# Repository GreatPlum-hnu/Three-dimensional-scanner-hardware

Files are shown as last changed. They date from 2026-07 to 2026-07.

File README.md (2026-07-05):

# 三维重建硬件资料说明

本目录内容用于个人学习、研究和自用记录，主要整理手持式激光雷达与相机融合三维重建相关的硬件清单、连接关系和选型备注。

## 使用声明

- 本项目仅供个人学习、实验和资料整理使用，不用于商业用途。
- 文档中的品牌、型号、链接和资料名称仅用于说明硬件选型和技术参考，不代表与相关品牌或厂商存在合作关系。
- 文档中的价格、链接和参数可能会随时间变化，实际采购前请以官方资料、商家页面和设备手册为准。
- 如文档中引用或整理的资料未正确标注来源，或涉及版权、署名、链接失效等问题，请联系作者，我会及时补充来源、修改内容或删除相关信息。

## 内容范围

- 三维重建硬件清单
- 雷达、相机、同步器、供电、支架和外壳等选型记录
- 系统连接关系和采购注意事项
- 相关官方资料和参考链接

## 文档阅读顺序

1. [三维重建硬件清单](三维重建硬件清单.md)
2. [FAST-LIVO2 前端建图环境安装教程（fishros 版）](FAST-LIVO2前端建图环境安装教程-fishros版.md)
3. [FAST-LIVO2 前端建图硬件同步器与驱动安装（MID360 版）](FAST-LIVO2前端建图硬件同步器与驱动安装-MID360版.md)
4. [FAST-LIVO2 前端建图相机内参与雷达相机外参标定教程](FAST-LIVO2前端建图相机内参与雷达相机外参标定教程.md)
5. [FAST-LIVO2 输出数据导入 Postshot 高斯泼溅重建教程](FAST-LIVO2输出数据导入Postshot高斯泼溅重建教程.md)

## 一键启动

完成环境安装、驱动配置、相机内参标定和雷达-相机外参标定后，可以使用启动脚本：

```bash
./scripts/start_fast_livo_mid360.sh
```

当前默认使用 `mapping_avia.launch` 做启动测试。正式 MID360 三维重建时，应将 `FAST_LIVO_LAUNCH` 设置为已经完成标定配置的 MID360 launch 文件。

## 免责声明

本文档不构成产品推荐、采购承诺或工程交付文件。实际搭建、接线、供电和调试过程中，请遵守设备厂商说明，确认电压、电流、线序、极性和接口兼容性。因自行使用本文档内容造成的设备损坏、数据损失或其他风险，由使用者自行承担。

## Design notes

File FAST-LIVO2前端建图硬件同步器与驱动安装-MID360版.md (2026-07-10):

# FAST-LIVO2 前端建图硬件同步器与驱动安装教程（MID360 版）

本文档基于 `scan2.world` 的 FAST-LIVO2 手持三维重建设备教程 2 重新整理，只保留 Livox MID360 相关内容。

本版不包含 AVIA、Livox-SDK、livox_ros_driver 的安装流程。MID360 应使用：

- Livox-SDK2
- livox_ros_driver2
- ROS1 Noetic
- Hikrobot MVS / mvs_ros_driver

本文档优先使用 `LIV_handhold` 中的 `livox_ros_driver2` 和 `mvs_ros_driver`，因为该仓库的驱动包含面向 FAST-LIVO2 手持三维重建设备的硬件同步适配。官方 `Livox-SDK/livox_ros_driver2` 可用于 MID360 基础点云测试，但不能替代相机驱动和整套同步方案。

## 一、准备内容

建议先完成上一篇环境安装：

- Ubuntu 20.04
- ROS Noetic
- FAST-LIVO2 工作空间
- Catkin 编译环境

硬件侧准备：

- Livox MID360
- 海康工业相机
- 硬件同步器
- MID360 网线 / 一分三线缆
- 相机 USB 线
- 稳定供电模块

## 二、硬件同步器制作说明

原教程的硬件同步器制作过程主要通过图片展示。整理为 MID360 版本时，重点保留以下连接关系：

- MID360：通过网口连接主机，通过供电线接入电源。
- 海康相机：通过 USB 连接主机，通过触发线接入同步器。
- 同步器：负责给相机提供外部触发信号，并与系统供电共地。
- 主机：同时接收 MID360 的点云 / IMU 数据和相机图像数据。

制作和接线时请重点确认：

- 电源电压和电流满足 MID360、相机和同步器要求。
- GND 必须共地。
- 相机触发线极性正确。
- MID360 使用网口通信，不使用 AVIA 的串口配置方式。
- 所有线序以设备手册、同步器原理图和实际接口定义为准。

## 三、安装海康 MVS 驱动

到海康机器人官网下载对应 Linux 版本的 MVS 客户端和 SDK：

```text
https://www.hikrobotics.com/cn/machinevision/service/download/?module=0
```

安装完成后，可以进入 MVS 目录测试软件是否能打开：

```bash
cd /opt/MVS/bin
export LD_LIBRARY_PATH=/opt/MVS/bin/:$LD_LIBRARY_PATH
./MVS
```

如果 `./MVS` 无法启动，也可以尝试：

```bash
./MVS.sh
```

确认 MVS 能识别相机后，再继续配置 ROS 驱动。

注意：使用 ROS 驱动打开相机前，请关闭 MVS 客户端，避免相机被 MVS 占用导致 ROS 驱动无法打开设备。

## 四、安装 Livox-SDK2

MID360 使用 Livox-SDK2，不使用 Livox-SDK。

先确认基础编译工具已安装：

```bash
sudo apt update
sudo apt install -y git cmake build-essential
```

执行：

```bash
cd ~
git clone https://github.com/Livox-SDK/Livox-SDK2.git
cd Livox-SDK2
mkdir -p build
cd build
cmake ..
make -j$(nproc)
sudo make install
sudo ldconfig
```

如果电脑内存较小，可以将 `make -j$(nproc)` 改为：

```bash
make -j2
```

如果后续启动驱动时提示找不到 Livox SDK2 的动态库，可以临时执行：

```bash
export LD_LIBRARY_PATH=${LD_LIBRARY_PATH}:/usr/local/lib
```

也可以写入 `~/.bashrc`：

```bash
echo 'export LD_LIBRARY_PATH=${LD_LIBRARY_PATH}:/usr/local/lib' >> ~/.bashrc
source ~/.bashrc
```

## 五、下载 MID360 和相机 ROS 驱动

本文档统一使用已有的 `~/catkin_ws` 作为 ROS1 工作空间。进入工作空间 `src` 目录：

```bash
mkdir -p ~/catkin_ws/src
cd ~/catkin_ws/src
```

下载三维重建手持设备驱动仓库：

```bash
git clone https://github.com/xuankuzcr/LIV_handhold.git
```

如果仓库中已经包含 `livox_ros_driver2` 和 `mvs_ros_driver`，将它们移动到当前工作空间的 `src` 下：

```bash
mv LIV_handhold/livox_ros_driver2 ./
mv LIV_handhold/mvs_ros_driver ./
```

如果该仓库内容发生变化，也可以直接下载官方 MID360 驱动：

```bash
git clone https://github.com/Livox-SDK/livox_ros_driver2.git
```

注意：官方 `livox_ros_driver2` 只能补充雷达 ROS 驱动，不能提供 `mvs_ros_driver`。相机 ROS 驱动仍需要从 `LIV_handhold` 或后续官方同步器配套仓库中获取。

目录建议保持为：

```text
catkin_ws
└── src
    ├── livox_ros_driver2
    └── mvs_ros_driver
```

## 六、编译 MID360 和相机 ROS 驱动

MID360 的 `livox_ros_driver2` 同时支持 ROS1 和 ROS2。ROS Noetic 下要明确使用 ROS1。

优先使用 `livox_ros_driver2` 的构建脚本。该脚本会回到工作空间根目录执行 `catkin_make`，因此同一工作空间中的 `mvs_ros_driver` 也会一起编译：

```bash
cd ~/catkin_ws/src/livox_ros_driver2
source /opt/ros/noetic/setup.bash
./build.sh ROS1
```

如果你使用的驱动包要求在工作空间根目录编译，建议只编译驱动相关包，避免同一工作空间中的其他包影响本步骤：

```bash
cd ~/catkin_ws
catkin_make -DROS_EDITION=ROS1 -DCATKIN_WHITELIST_PACKAGES="livox_ros_driver2;mvs_ros_driver"
```

编译完成后，如果后续需要恢复整个工作空间编译，可以清空白名单：

```bash
catkin_make -DCATKIN_WHITELIST_PACKAGES=""
```

如果后续要运行 FAST-LIVO2，还需要把 FAST-LIVO2 及其依赖包一起编译。由于当前工作空间中的 `livox_camera_calib` 可能会因为 PCL / libusb 链接问题影响整体编译，可以继续使用白名单方式，跳过 `livox_camera_calib`：

```bash
cd ~/catkin_ws
catkin_make -DROS_EDITION=ROS1 -DCATKIN_WHITELIST_PACKAGES="livox_ros_driver2;mvs_ros_driver;vikit_common;vikit_ros;vikit_py;fast_livo"
```

编译完成后加载环境：

```bash
source ~/catkin_ws/devel/setup.bash
```

检查两个 ROS 包是否都能被找到：

```bash
rospack find livox_ros_driver2
rospack find mvs_ros_driver
```

建议写入 `~/.bashrc`：

```bash
echo "source ~/catkin_ws/devel/setup.bash" >> ~/.bashrc
source ~/.bashrc
```

## 七、配置 MID360 网络

MID360 使用静态 IP。常见规则是：

```text
MID360 IP: 192.168.1.1XX
```

其中 `XX` 通常对应 MID360 序列号最后两位。比如序列号最后两位是 `02`，设备 IP 可能是：

```text
192.168.1.102
```

主机有线网卡需要设置到同一网段，例如：

```text
IP 地址:   192.168.1.5
子网掩码: 255.255.255.0
网关:     192.168.1.1
```

设置完成后，测试是否能 ping 通 MID360：

```bash
ping 192.168.1.102
```

请把 `192.168.1.102` 替换为你的 MID360 实际 IP。

## 八、修改 MID360 配置文件

配置文件通常位于：

```bash
~/catkin_ws/src/livox_ros_driver2/config/MID360_config.json
```

需要重点修改两类 IP：

- `host_net_info`：主机有线网卡 IP，例如 `192.168.1.5`
- `lidar_configs`：MID360 的实际 IP，例如 `192.168.1.102`

典型配置片段如下：

```json
{
  "lidar_summary_info": {
    "lidar_type": 8
  },
  "MID360": {
    "lidar_net_info": {
      "cmd_data_port": 56100,
      "push_msg_port": 56200,
      "point_data_port": 56300,
      "imu_data_port": 56400,
      "log_data_port": 56500
    },
    "host_net_info": {
      "cmd_data_ip": "192.168.1.5",
      "cmd_data_port": 56101,
      "push_msg_ip": "192.168.1.5",
      "push_msg_port": 56201,
      "point_data_ip": "192.168.1.5",
      "point_data_port": 56301,
      "imu_data_ip": "192.168.1.5",
      "imu_data_port": 56401,
      "log_data_ip": "",
      "log_data_port": 56501
    }
  },
  "lidar_configs": [
    {
      "ip": "192.168.1.102",
      "pcl_data_type": 1,
      "pattern_mode": 0,
      "extrinsic_parameter": {
        "roll": 0.0,
        "pitch": 0.0,
        "yaw": 0.0,
        "x": 0,
        "y": 0,
        "z": 0
      }
    }
  ]
}
```

注意：

- 不要把 AVIA 的 `broadcast_code` 配置方式用于 MID360。
- MID360 主要改 IP，不是改序列号。
- 多个 MID360 时，需要在 `lidar_configs` 中添加多个设备配置。

下面以我的电脑为例，说明实际需要检查哪些文件。

我的 `livox_ros_driver2` 放在下面这个工作空间：

```bash
~/catkin_ws/src/livox_ros_driver2
```

如果只使用一台 MID360，主要会用到下面几个 launch 文件：

```text
~/catkin_ws/src/livox_ros_driver2/launch_ROS1/msg_MID360.launch
~/catkin_ws/src/livox_ros_driver2/launch_ROS1/rviz_MID360.launch
~/catkin_ws/src/livox_ros_driver2/launch_ROS1/mid360.launch
```

打开这几个 launch 文件，可以看到它们都引用同一个配置文件：

```text
$(find livox_ros_driver2)/config/MID360_config.json
```

所以单 MID360 方案真正需要重点检查的是：

```bash
~/catkin_ws/src/livox_ros_driver2/config/MID360_config.json
```

以我的电脑为例，`MID360_config.json` 中的主机 IP 已经改成 `192.168.1.4`：

```json
"host_net_info": {
  "cmd_data_ip": "192.168.1.4",
  "push_msg_ip": "192.168.1.4",
  "point_data_ip": "192.168.1.4",
  "imu_data_ip": "192.168.1.4"
}
```

这里的 `192.168.1.4` 是我的电脑连接 MID360 所在网段的 IP。你实际配置时，需要改成你自己电脑连接 MID360 的网卡 IP。

同一个文件中，MID360 雷达 IP 已经改成 `192.168.1.165`：

```json
"lidar_configs": [
  {
    "ip": "192.168.1.165"
  }
]
```

再检查 launch 文件中的序列号。以我的 MID360 为例，序列号是 `47MCNCP0036165`：

```xml
<arg name="bd_list" default="47MCNCP0036165"/>
```

这个序列号需要在下面几个单 MID360 launch 文件中保持一致：

```text
msg_MID360.launch
rviz_MID360.launch
mid360.launch
```

另外，`mixed_HAP_MID360_config.json` 不是单 MID360 方案的主配置文件。它只在运行混合设备 launch 时使用：

```text
msg_mixed.launch
rviz_mixed.launch
```

所以如果只接一台 MID360，不需要修改 `mixed_HAP_MID360_config.json`。

## 九、修改相机配置文件

相机配置文件通常位于：

```bash
~/catkin_ws/src/mvs_ros_driver/config/left_camera_trigger.yaml
```

检查触发模式和像素格式。

建议重点检查：

```yaml
TopicName: "left_camera/image"
TriggerEnable: 1
```

其中 `TriggerEnable: 1` 表示使用外部触发。如果只是临时测试相机、没有接同步器触发信号，可以改为 `0` 做无触发出图测试，正式录制时再改回 `1`。

原教程中提到，如果使用海康 `MV-CU013-A0UC`，需要将 `PixelFormat` 改为 `4`：

```yaml
PixelFormat: 4
```

常见含义：

```text
0: RGB8
1: BayerRG8
2: BayerRG12Packed
3: BayerGB12Packed
4: BayerGB8
```

如果你的相机型号不同，请以 MVS 中能正常出图的像素格式为准。

## 十、启动 MID360 驱动

加载工作空间：

```bash
source ~/catkin_ws/devel/setup.bash
```

启动 MID360 自定义消息格式驱动：

```bash
roslaunch livox_ros_driver2 msg_MID360.launch
```

如果只是想用 RViz 检查点云显示，可以使用：

```bash
roslaunch livox_ros_driver2 rviz_MID360.launch
```

检查话题：

```bash
rostopic list
```

应能看到类似话题：

```text
/livox/lidar
/livox/imu
```

继续检查话题类型和频率：

```bash
rostopic type /livox/lidar
rostopic type /livox/imu
rostopic hz /livox/lidar
rostopic hz /livox/imu
```

使用 `msg_MID360.launch` 时，`/livox/lidar` 通常应为 `livox_ros_driver2/CustomMsg`。

## 十一、启动海康相机驱动

新开一个终端：

```bash
source ~/catkin_ws/devel/setup.bash
roslaunch mvs_ros_driver mvs_camera_trigger.launch
```

检查相机话题：

```bash
rostopic list | grep camera
```

常见图像话题：

```text
/left_camera/image
```

继续检查图像频率：

```bash
rostopic hz /left_camera/image
```

## 十二、录制 MID360 + 相机数据包

确认 MID360 和相机驱动都启动后，录制 rosbag：

```bash
rosbag record /livox/lidar /livox/imu /left_camera/image
```

也可以指定输出文件名：

```bash
rosbag record -O mid360_livo_data.bag /livox/lidar /livox/imu /left_camera/image
```

录制完成后查看数据包信息：

```bash
rosbag info mid360_livo_data.bag
```

确认其中包含：

```text
/livox/lidar
/livox/imu
/left_camera/image
```

## 十三、验证硬件同步是否生效

录制 bag 包后，可以直接查看雷达和相机话题前两帧的 header 时间戳：

```bash
rostopic echo -b <rosbag_name.bag> -n 2 /livox/lidar/header
rostopic echo -b <rosbag_name.bag> -n 2 /left_camera/image/header

# 如果 bag 中录制的是压缩图像话题，则使用：
rostopic echo -b <rosbag_name.bag> -n 2 /left_camera/image/compressed/header
```

将 `<rosbag_name.bag>` 替换为实际的 bag 文件名，例如 `mid360_livo_data.bag`。对比雷达与相机 header 中的 `stamp` 字段，检查时间戳是否正常且无明显跳变。

如果是在采集现场验证实时硬件同步，可以保持雷达和相机驱动运行，再检查相机触发频率是否稳定：

```bash
rostopic hz /left_camera/image
```

如果同步器输出的是 10 Hz 触发信号，相机图像频率应接近 10 Hz。不同同步器固件或配置的触发频率可能不同，请以实际同步器说明为准。

同步异常时常见现象：

- `/left_camera/image` 没有频率，说明相机没有收到触发信号或触发配置不正确。
- 图像频率明显不稳定，可能是触发线、曝光时间、USB 带宽或相机配置问题。
- 雷达、IMU、图像时间戳存在明显跳变，可能是同步器固件、主机时间或驱动配置问题。

## 十四、运行 FAST-LIVO2

本节中的 FAST-LIVO2 启动仅用于测试环境、驱动、话题和程序是否能跑通。当前还没有完成相机内参标定，也没有完成相机与雷达之间的外参标定，因此这里运行得到的结果只能作为联调参考，不能作为正式三维重建结果。

当前 FAST-LIVO2 工程中还没有 `mapping_mid360.launch`，已有的 launch 文件是官方示例配置。可以先使用 `mapping_avia.launch` 启动，验证 FAST-LIVO2 主程序、雷达话题和相机话题能否跑通。

如果前面只编译了 `livox_ros_driver2` 和 `mvs_ros_driver`，这里需要先确认 FAST-LIVO2 也已经编译：

```bash
cd ~/catkin_ws
catkin_make -DROS_EDITION=ROS1 -DCATKIN_WHITELIST_PACKAGES="livox_ros_driver2;mvs_ros_driver;vikit_common;vikit_ros;vikit_py;fast_livo"
source ~/catkin_ws/devel/setup.bash
```

确认 FAST-LIVO2 包能被 ROS 找到：

```bash
rospack find fast_livo
```

进入 FAST-LIVO2 工作空间环境：

```bash
source ~/catkin_ws/devel/setup.bash
```

查看当前已有 launch 文件：

```bash
ls ~/catkin_ws/src/FAST-LIVO2/launch
```

如果没有 `mapping_mid360.launch`，不要执行：

```bash
roslaunch fast_livo mapping_mid360.launch
```

否则会出现：

```text
RLException: [mapping_mid360.launch] is neither a launch file in package [fast_livo]
```

当前先使用已有的 AVIA 示例 launch 启动：

```bash
roslaunch fast_livo mapping_avia.launch
```

注意：`mapping_avia.launch` 只是当前阶段的启动验证方式，不代表已经完成 MID360 最终适配。它会加载：

```text
~/catkin_ws/src/FAST-LIVO2/config/avia.yaml
~/catkin_ws/src/FAST-LIVO2/config/camera_pinhole.yaml
```

其中 `avia.yaml` 虽然已经使用下面这些话题：

```yaml
img_topic: "/left_camera/image"
lid_topic: "/livox/lidar"
imu_topic: "/livox/imu"
```

但它仍然是 AVIA 示例配置。后续正式使用 MID360 时，需要复制并整理出 MID360 专用配置，例如：

```text
mapping_mid360.launch
mid360.yaml
camera_mid360.yaml
```

并重点确认以下内容已经改成 MID360 对应参数：

- 雷达话题：`/livox/lidar`
- IMU 话题：`/livox/imu`
- 相机话题：`/left_camera/image`
- 雷达到相机外参
- 时间同步参数
- MID360 点云格式
- 相机内参和畸变参数

播放录制好的数据包：

```bash
source ~/catkin_ws/devel/setup.bash
rosbag play mid360_livo_data.bag
```

完成所有配置和标定后，也可以使用项目中的一键启动脚本：

```bash
cd ~/Three-dimensional-scanner-hardware
./scripts/start_fast_livo_mid360.sh
```

如果后续已经创建了正式的 MID360 launch 文件，可以指定：

```bash
FAST_LIVO_LAUNCH=mapping_mid360.launch ./scripts/start_fast_livo_mid360.sh
```

## 十五、常见问题

### 1. 能 ping 通 MID360，但没有点云话题

检查：

- `MID360_config.json` 中主机 IP 是否等于有线网卡 IP。
- `lidar_configs` 中 MID360 IP 是否正确。
- 是否启动了 `msg_MID360.launch`。
- 防火墙是否拦截 UDP 数据。

### 2. 启动驱动时提示找不到 Livox SDK2 动态库

执行：

```bash
export LD_LIBRARY_PATH=${LD_LIBRARY_PATH}:/usr/local/lib
```

然后重新启动驱动。

### 3. catkin_make 编译时报 livox_camera_calib 链接错误

如果执行：

```bash
catkin_make -DROS_EDITION=ROS1
```

出现类似错误：

```text
libpcl_io.so: undefined reference to `libusb_set_option'
livox_camera_calib/CMakeFiles/lidar_camera_calib.dir/all
```

说明当前失败的是 `livox_camera_calib`，不是 `livox_ros_driver2`、`mvs_ros_driver` 或 FAST-LIVO2。可以用白名单跳过 `livox_camera_calib`。

如果只测试驱动，可以只编译驱动相关包：

```bash
cd ~/catkin_ws
catkin_make -DROS_EDITION=ROS1 -DCATKIN_WHITELIST_PACKAGES="livox_ros_driver2;mvs_ros_driver"
source ~/catkin_ws/devel/setup.bash
```

如果还要运行 FAST-LIVO2，需要把 FAST-LIVO2 及其依赖一起加入白名单：

```bash
cd ~/catkin_ws
catkin_make -DROS_EDITION=ROS1 -DCATKIN_WHITELIST_PACKAGES="livox_ros_driver2;mvs_ros_driver;vikit_common;vikit_ros;vikit_py;fast_livo"
source ~/catkin_ws/devel/setup.bash
```

确认驱动包能被找到：

```bash
rospack find livox_ros_driver2
rospack find mvs_ros_driver
rospack find fast_livo
```

`livox_camera_calib` 属于后续雷达-相机外参标定相关内容，可以在需要标定时再单独处理。

### 4. FAST-LIVO2 编译时报 libusb_set_option 链接错误

如果编译 FAST-LIVO2 时出现类似错误：

```text
/usr/bin/ld: .../libpcl_io.so: undefined reference to `libusb_set_option'
collect2: error: ld returned 1 exit status
FAST-LIVO2/CMakeFiles/fastlivo_mapping.dir/all
```

说明 `fastlivo_mapping` 在链接 `libpcl_io.so` 时，没有把 `libusb-1.0` 一起链接进去。`libpcl_io` 内部依赖 libusb，部分 Ubuntu / PCL 组合下这个依赖不会自动传递到最终可执行文件。

先确认 libusb 开发包已经安装：

```bash
sudo apt install -y libusb-1.0-0-dev
pkg-config --libs libusb-1.0
```

正常应输出：

```text
-lusb-1.0
```

然后修改 FAST-LIVO2 的 CMake 配置：

```bash
vim ~/catkin_ws/src/FAST-LIVO2/CMakeLists.txt
```

在 `target_link_libraries(fastlivo_mapping ... )` 中加入：

```cmake
usb-1.0
```

修改后类似：

```cmake
target_link_libraries(fastlivo_mapping
  laser_mapping
  vio
  lio
  pre
  imu_proc
  ${catkin_LIBRARIES}
  ${PCL_LIBRARIES}
  ${OpenCV_LIBRARIES}
  ${Sophus_LIBRARIES}
  ${Boost_LIBRARIES}
  usb-1.0
)
```

重新编译：

```bash
cd ~/catkin_ws
catkin_make -DROS_EDITION=ROS1 -DCATKIN_WHITELIST_PACKAGES="livox_ros_driver2;mvs_ros_driver;vikit_common;vikit_ros;vikit_py;fast_livo"
source ~/catkin_ws/devel/setup.bash
```

### 5. FAST-LIVO2 运行时报 libpcl_io.so undefined symbol

如果执行：

```bash
roslaunch fast_livo mapping_avia.launch
```

启动后 `laserMapping` 立刻退出，并出现类似错误：

```text
/home/zhuzhe/catkin_ws/devel/lib/fast_livo/fastlivo_mapping: symbol lookup error:
/usr/lib/x86_64-linux-gnu/libpcl_io.so.1.10: undefined symbol: libusb_set_option
```

说明运行时加载到了不合适的 `libusb-1.0.so.0`。以我的电脑为例，`LD_LIBRARY_PATH` 中 `/opt/MVS/lib/64` 排在系统库前面，导致 PCL 加载了海康 MVS 自带的 `libusb`，而不是系统自带的 `libusb`。

可以用下面命令检查：

```bash
ldd ~/catkin_ws/devel/lib/fast_livo/fastlivo_mapping | grep libusb
ldd /usr/lib/x86_64-linux-gnu/libpcl_io.so.1.10 | grep libusb
```

如果看到：

```text
libusb-1.0.so.0 => /opt/MVS/lib/64/libusb-1.0.so.0
```

就说明动态库搜索顺序有问题。

临时解决方法是在启动 FAST-LIVO2 的终端中，把系统库路径放到 MVS 路径前面：

```bash
export LD_LIBRARY_PATH=/lib/x86_64-linux-gnu:/usr/lib/x86_64-linux-gnu:/opt/MVS/lib/64:/opt/MVS/lib/32:$LD_LIBRARY_PATH
source ~/catkin_ws/devel/setup.bash
roslaunch fast_livo mapping_avia.launch
```

长期建议：

- 不要在 `~/.bashrc` 中把 `/opt/MVS/lib/64` 放在 `LD_LIBRARY_PATH` 最前面。
- 如果需要配置 MVS 库路径，优先放在系统库路径后面。
- 启动 MVS 客户端和启动 FAST-LIVO2 可以使用不同终端，避免 MVS 的库路径污染 FAST-LIVO2 的运行环境。

### 6. FAST-LIVO2 提示 image has not the same size as the camera model

如果启动 FAST-LIVO2 后出现类似错误：

```text
terminate called after throwing an instance of 'std::runtime_error'
what():  Frame: provided image has not the same size as the camera model
```

说明 FAST-LIVO2 收到的图像尺寸，和相机模型配置文件中的尺寸不一致。

以我的电脑为例，FAST-LIVO2 当前加载的是：

```bash
~/catkin_ws/src/FAST-LIVO2/config/camera_pinhole.yaml
```

其中相机模型尺寸为：

```yaml
cam_width: 1280
cam_height: 1024
scale: 1
```

而相机驱动配置文件：

```bash
~/catkin_ws/src/mvs_ros_driver/config/left_camera_trigger.yaml
```

中设置了：

```yaml
image_scale: 0.5
```

这会导致相机驱动发布缩放后的图像，实际图像尺寸可能变成 `640 x 512`，与 FAST-LIVO2 中的 `1280 x 1024` 相机模型不匹配。

临时验证时，建议先让相机驱动发布原始尺寸图像：

```yaml
image_scale: 1
```

修改后重新启动相机驱动和 FAST-LIVO2：

```bash
source ~/catkin_ws/devel/setup.bash
roslaunch mvs_ros_driver mvs_camera_trigger.launch
```

另开终端：

```bash
export LD_LIBRARY_PATH=/lib/x86_64-linux-gnu:/usr/lib/x86_64-linux-gnu:/opt/MVS/lib/64:/opt/MVS/lib/32:$LD_LIBRARY_PATH
source ~/catkin_ws/devel/setup.bash
roslaunch fast_livo mapping_avia.launch
```

也可以保留 `image_scale: 0.5`，但需要同步修改 FAST-LIVO2 的相机模型尺寸和内参，例如将宽高、`cam_fx`、`cam_fy`、`cam_cx`、`cam_cy` 按相同缩放比例调整。正式使用时建议重新标定相机内参，并保持相机驱动输出尺寸与 FAST-LIVO2 相机配置一致。

### 7. 相机打不开或没有图像

检查：

- MVS 软件是否能识别相机。
- USB 权限是否正常。
- `left_camera_trigger.yaml` 中 `PixelFormat` 是否匹配相机。
- 外部触发线是否接好。
- 同步器是否在输出触发信号。

### 8. 相机驱动提示 Shared trigger timestamp is unavailable

如果启动相机驱动时出现类似提示：

```text
[WARN] Shared trigger timestamp is unavailable, stale, or not increasing; using ros::Time::now() for image stamps.
```

含义是：相机驱动没有拿到可用的共享触发时间戳，所以临时使用 `ros::Time::now()` 作为图像时间戳。此时相机可能仍然可以出图，但图像时间戳不是硬件同步器提供的触发时间。

在当前 `mvs_ros_driver` 中，相机驱动会读取下面这个共享时间戳文件：

```bash
~/timeshare
```

可以检查文件是否存在：

```bash
ls -l ~/timeshare
stat ~/timeshare
```

如果文件不存在、没有持续更新，或者其中的时间戳和当前系统时间相差太大，驱动就会打印这个 warning。

以我的电脑为例，`~/timeshare` 文件存在，但其中的时间戳没有持续更新，且和当前系统时间相差超过驱动允许范围，因此相机驱动会退回到 `ros::Time::now()`。

排查顺序：

- 确认硬件同步器已经上电并输出触发信号。
- 确认相机配置中 `TriggerEnable: 1`，并且 `TriggerLine`、`TriggerActivation` 与实际接线一致。
- 确认负责写入 `~/timeshare` 的同步程序或驱动已经启动。
- 使用 `stat ~/timeshare` 观察文件修改时间是否随触发持续变化。
- 如果只是临时测试相机出图，可以先接受该 warning；如果要录制 FAST-LIVO2 数据，需要解决共享触发时间戳问题。

### 9. rosbag 里没有图像或 IMU

分别检查话题：

```bash
rostopic hz /livox/imu
rostopic hz /livox/lidar
rostopic hz /left_camera/image
```

如果某个话题没有频率，说明对应驱动或硬件连接还没有正常工作。

## 十六、参考链接

- 原教程：FAST-LIVO2（手持设备）教程2：硬件同步器的制作与驱动安装  
  https://www.scan2.world/blog/3
- Livox ROS Driver 2  
  https://github.com/Livox-SDK/livox_ros_driver2
- Livox-SDK2  
  https://github.com/Livox-SDK/Livox-SDK2
- LIV_handhold  
  https://github.com/xuankuzcr/LIV_handhold
- 海康机器人 MVS 下载  
  https://www.hikrobotics.com/cn/machinevision/service/download/?module=0

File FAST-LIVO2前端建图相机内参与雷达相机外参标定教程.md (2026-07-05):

# FAST-LIVO2 前端建图相机内参与雷达相机外参标定教程

文档顺序：4

本文档用于说明手持三维重建设备在完成硬件安装、驱动安装和基础联调后，如何进行相机内参标定，以及相机与 MID360 雷达之间的外参标定。

在完成本文档之前，`mapping_avia.launch` 只能用于测试 FAST-LIVO2 主程序、雷达话题和相机话题是否能跑通。没有完成标定时，不应将运行结果作为正式三维重建结果。

## 一、标定目标

三维重建系统至少需要两类标定结果：

- 相机内参：描述相机自身成像模型，包括焦距、主点、畸变参数和图像尺寸。
- 雷达-相机外参：描述雷达坐标系和相机坐标系之间的位置与姿态关系。

FAST-LIVO2 中主要会用到这些配置文件：

```text
~/catkin_ws/src/FAST-LIVO2/config/camera_pinhole.yaml
~/catkin_ws/src/FAST-LIVO2/config/avia.yaml
```

当前仍然使用 `mapping_avia.launch` 做联调测试，后续正式使用 MID360 时，建议复制并整理出专用配置：

```text
mapping_mid360.launch
mid360.yaml
camera_mid360.yaml
```

## 二、标定前准备

标定前先确认：

- MID360 和相机已经刚性固定在支架上。
- 标定完成前后不要移动相机、镜头、雷达和支架。
- 相机镜头焦距、光圈、对焦位置已经固定。
- 相机图像输出尺寸已经确定，例如 `1280 x 1024`。
- 相机驱动中的 `image_scale` 和 FAST-LIVO2 相机配置中的尺寸一致。

如果 `left_camera_trigger.yaml` 中设置：

```yaml
image_scale: 1
```

那么 FAST-LIVO2 相机配置中应保持原始尺寸，例如：

```yaml
cam_width: 1280
cam_height: 1024
scale: 1
```

如果使用 `image_scale: 0.5`，则需要同步调整 FAST-LIVO2 的相机模型尺寸和内参。正式标定时建议先使用原始尺寸。

## 三、相机内参标定

相机内参可以使用 OpenCV、ROS `camera_calibration` 或海康 MVS 采图后离线标定。本文推荐先用 ROS 工具完成标定。

安装标定工具：

```bash
sudo apt install -y ros-noetic-camera-calibration
```

启动相机驱动：

```bash
source ~/catkin_ws/devel/setup.bash
roslaunch mvs_ros_driver mvs_camera_trigger.launch
```

确认图像话题和尺寸：

```bash
rostopic list | grep image
rostopic echo -n 1 /left_camera/image/width
rostopic echo -n 1 /left_camera/image/height
```

如果 `rostopic echo /left_camera/image/width` 无法直接读取，也可以查看完整图像消息：

```bash
rostopic echo -n 1 /left_camera/image
```

使用棋盘格标定板进行标定。下面以 `8 x 6` 内角点、每个格子 `0.15 m` 为例，实际参数需要按你的标定板修改：

```bash
rosrun camera_calibration cameracalibrator.py \
  --size 8x6 \
  --square 0.15 \
  image:=/left_camera/image
```

采集时让标定板出现在画面不同位置和不同角度：

- 靠近画面中心、四角和边缘。
- 有正视、倾斜、远近变化。
- 保证图案清晰，不要过曝或运动模糊。
- 标定过程中不要改变镜头焦距和对焦。

标定完成后记录：

- 图像宽高。
- `fx`、`fy`、`cx`、`cy`。
- 畸变参数 `d0`、`d1`、`d2`、`d3`。

## 四、写入 FAST-LIVO2 相机配置

将相机内参写入：

```bash
~/catkin_ws/src/FAST-LIVO2/config/camera_pinhole.yaml
```

配置示例：

```yaml
cam_model: Pinhole
cam_width: 1280
cam_height: 1024
scale: 1
cam_fx: 1298.6550242665473
cam_fy: 1297.9353131134299
cam_cx: 627.2691200086692
cam_cy: 485.3881646195598
cam_d0: -0.07356933181806001
cam_d1: 0.08039469627671299
cam_d2: -0.000706232243829042
cam_d3: -0.000518274892345108
```

注意：上面的数值是当前工程中的示例值。正式使用时，需要替换成你自己相机和镜头的标定结果。

## 五、雷达-相机外参标定

外参标定参考 `scan2.world` 的 FAST-LIVO2 手持设备外参标定教程：

```text
https://www.scan2.world/blog/5
```

该教程使用 `FAST-Calib` 进行外参标定。它需要准备手持设备、标定板、雷达点云和对应图像。

外参标定时需要注意：

- 平稳放置手持设备，让相机和雷达同时看到完整标定板。
- 开始采集后不要移动手持设备和标定板。
- 如果做多场景联合标定，可以从不同角度采集多组数据，建议至少三个角度。
- 每组数据都要保证雷达点云和相机图像中标定板清晰可见。

## 六、准备外参标定数据

启动雷达驱动：

```bash
source ~/catkin_ws/devel/setup.bash
roslaunch livox_ros_driver2 msg_MID360.launch
```

启动相机驱动：

```bash
source ~/catkin_ws/devel/setup.bash
roslaunch mvs_ros_driver mvs_camera_trigger.launch
```

查看相机画面：

```bash
rqt_image_view
```

录制雷达和相机数据，建议每组大约 10 秒：

```bash
rosbag record -O calib_mid360_camera.bag /livox/lidar /left_camera/image
```

如果你的外参标定流程需要 IMU，也可以一起录制：

```bash
rosbag record -O calib_mid360_camera.bag /livox/lidar /livox/imu /left_camera/image
```

从 rosbag 中解出一张清晰图像，用于 FAST-Calib 配置。可以播放数据包并使用 `rqt_image_view` 保存图像：

```bash
roscore
```

新开终端：

```bash
rqt_image_view
```

再新开终端：

```bash
rosbag play calib_mid360_camera.bag
```

保存图像后，记录图像路径和 rosbag 路径，后续写入 FAST-Calib 配置文件。

## 七、安装并编译 FAST-Calib

建议单独建立一个标定工作空间：

```bash
mkdir -p ~/calib_ws/src
cd ~/calib_ws/src
git clone https://github.com/hku-mars/FAST-Calib.git
```

检查依赖：

```bash
dpkg -l | grep libpcl
opencv_version
```

编译：

```bash
cd ~/calib_ws
catkin_make
source ~/calib_ws/devel/setup.bash
```

如果编译时出现 PCL / libusb 相关问题，例如：

```text
libpcl_io.so: undefined reference to `libusb_set_option'
```

通常是 PCL 链接到了海康 MVS 自带的旧版 `libusb`。可以先检查：

```bash
ldd /usr/lib/x86_64-linux-gnu/libpcl_io.so 2>/dev/null | grep -i usb
```

如果输出指向：

```text
/opt/MVS/lib/64/libusb-1.0.so.0
```

可以临时移除 MVS 库路径：

```bash
export LD_LIBRARY_PATH=$(echo $LD_LIBRARY_PATH | sed 's|/opt/MVS/lib/64:||g; s|/opt/MVS/lib/32:||g')
```

也可以显式指定系统 libusb：

```bash
export LD_PRELOAD=/lib/x86_64-linux-gnu/libusb-1.0.so.0
```

然后重新编译：

```bash
cd ~/calib_ws
catkin_make
```

## 八、配置 FAST-Calib

FAST-Calib 中需要重点检查：

- launch 文件：`calib.launch` 用于单场景标定。
- launch 文件：`multi_calib.launch` 用于多场景联合标定。
- 配置文件：`qr_params.yaml`。

`qr_params.yaml` 中通常需要配置：

- 相机内参：`fx`、`fy`、`cx`、`cy`、`k1`、`k2`、`p1`、`p2`。
- 标定板参数。
- rosbag 路径。
- 从 rosbag 中解出的图像路径。
- 输出路径。
- 点云距离滤波参数。

标定板参数需要按实际标定板填写，例如：

- `marker_size`：ArUco 二维码边长。
- `delta_width_qr_center`：两个二维码水平中心距的一半。
- `delta_height_qr_center`：两个二维码垂直中心距的一半。
- `delta_width_circles`：两个圆心水平距离。
- `delta_height_circles`：两个圆心垂直距离。
- `circle_radius`：圆形靶标半径。

如果过滤后的点云没有准确落在标定板附近，需要调整距离滤波参数。可以在 RViz 中订阅：

```text
/filtered_cloud
```

查看过滤后的点云是否只保留了标定板附近的点。

参考教程中也提到可以使用：

```bash
python src/FAST-Calib/scripts/distance_filter_tool.py <YOUR_CALIB_DATA_PATH> <YOUR_OUTPUT_PATH>
```

辅助获取距离滤波阈值。使用前需要确认脚本中的点云话题名称和你的 rosbag 一致，例如：

```python
topic_name="/livox/lidar"
```

## 九、运行 FAST-Calib 外参标定

单场景标定：

```bash
cd ~/calib_ws
source devel/setup.bash
roslaunch fast_calib calib.launch
```

标定完成后，在输出目录中查看结果文件，例如：

```text
output/single_calib_result.txt
```

多场景联合标定：

```bash
roslaunch fast_calib multi_calib.launch
```

多场景联合标定通常需要先运行至少三组单场景标定，使输出目录中生成多组记录，然后再运行 `multi_calib.launch`。

## 十、可选：使用 livox_camera_calib

本地工作空间中也已有 `livox_camera_calib`：

```text
~/catkin_ws/src/livox_camera_calib
```

它也可用于雷达-相机外参标定，通常需要准备同一场景下的图像文件和点云文件，例如：

```text
0.png
0.pcd
```

对应配置文件为：

```bash
~/catkin_ws/src/livox_camera_calib/config/calib.yaml
```

如果后续选择这条路线，需要根据该工具 README 单独配置 `image_file`、`pcd_file`、`camera_matrix`、`dist_coeffs` 和结果输出路径。

## 十一、写入 FAST-LIVO2 外参配置

FAST-LIVO2 中外参主要写在：

```bash
~/catkin_ws/src/FAST-LIVO2/config/avia.yaml
```

当前仍使用 `mapping_avia.launch` 做测试时，它会加载 `avia.yaml`。正式适配 MID360 时，建议复制出：

```bash
cp ~/catkin_ws/src/FAST-LIVO2/config/avia.yaml ~/catkin_ws/src/FAST-LIVO2/config/mid360.yaml
cp ~/catkin_ws/src/FAST-LIVO2/config/camera_pinhole.yaml ~/catkin_ws/src/FAST-LIVO2/config/camera_mid360.yaml
cp ~/catkin_ws/src/FAST-LIVO2/launch/mapping_avia.launch ~/catkin_ws/src/FAST-LIVO2/launch/mapping_mid360.launch
```

然后在 `mapping_mid360.launch` 中加载：

```xml
<rosparam command="load" file="$(find fast_livo)/config/mid360.yaml" />
<rosparam file="$(find fast_livo)/config/camera_mid360.yaml" />
```

外参相关字段示例：

```yaml
extrin_calib:
  extrinsic_T: [0.04165, 0.02326, -0.0284]
  extrinsic_R: [1, 0, 0,
                0, 1, 0,
                0, 0, 1]
  Rcl: [0.001850, -0.999997, -0.001953,
        0.394715,  0.002525, -0.918800,
        0.918802,  0.000929,  0.394718]
  Pcl: [0.012517, -0.146753, -0.012668]
```

注意：这里的示例值来自现有工程配置，不能直接作为最终 MID360 外参。需要根据 FAST-Calib 的输出结果和 FAST-LIVO2 对坐标方向的定义进行对应填写。

## 十二、标定结果检查

标定完成后，至少检查以下内容：

- 图像尺寸和 FAST-LIVO2 相机配置一致。
- 相机内参来自当前相机、当前镜头、当前分辨率。
- 雷达点云投影到图像时，边缘能和图像边缘基本重合。
- 手持轻微移动时，彩色点云没有明显重影。
- 标定后没有移动雷达、相机、镜头和支架。

如果出现以下现象，需要重新检查标定：

- 点云颜色整体偏移。
- 边缘投影左右或上下方向明显错位。
- 近处对齐、远处不对齐，或远处对齐、近处不对齐。
- 图像尺寸报错：`provided image has not the same size as the camera model`。
- FAST-LIVO2 运行时轨迹漂移明显，或者彩色点云重影严重。

## 十三、推荐流程

建议按下面顺序完成：

```text
1. 固定雷达、相机和镜头
2. 确认相机输出尺寸
3. 标定相机内参
4. 将内参写入 camera_pinhole.yaml 或 camera_mid360.yaml
5. 采集雷达-相机外参标定数据
6. 使用 FAST-Calib 求外参
7. 将外参写入 FAST-LIVO2 配置
8. 运行 FAST-LIVO2 验证投影、轨迹和彩色点云
```

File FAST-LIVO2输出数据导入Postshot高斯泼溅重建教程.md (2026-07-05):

# FAST-LIVO2 输出数据导入 Postshot 高斯泼溅重建教程

文档顺序：5

本文档说明在完成 FAST-LIVO2 联调、相机内参标定、雷达-相机外参标定后，如何将 FAST-LIVO2 输出的数据整理为 COLMAP 格式，并导入 Postshot 进行 3D Gaussian Splatting 高斯泼溅三维重建。

注意：Postshot 使用的是图像、相机内参和相机位姿。FAST-LIVO2 导出的 COLMAP 格式数据能让 Postshot 跳过传统 COLMAP SfM 求位姿步骤，直接使用 FAST-LIVO2 的轨迹结果进行训练。如果前面的相机内参、雷达-相机外参或轨迹质量不好，高斯泼溅结果会出现模糊、重影、漂浮物或尺度异常。

## 一、FAST-LIVO2 的 COLMAP 输出

FAST-LIVO2 本地源码中已经包含 COLMAP 输出逻辑。相关配置在：

```bash
~/catkin_ws/src/FAST-LIVO2/config/avia.yaml
```

关键配置为：

```yaml
pcd_save:
  pcd_save_en: true
  colmap_output_en: true
  interval: -1
```

其中：

- `pcd_save_en: true`：保存点云。
- `colmap_output_en: true`：输出 COLMAP 所需的文本文件和图像。
- `interval: -1`：将所有点云保存到一个文件中；数据量大时可能占用较多内存。

FAST-LIVO2 会将 COLMAP 相关文件输出到：

```text
~/catkin_ws/src/FAST-LIVO2/Log/Colmap
```

典型目录结构为：

```text
Log/Colmap
├── images
│   ├── 00001.png
│   ├── 00002.png
│   └── ...
└── sparse
    └── 0
        ├── cameras.txt
        ├── images.txt
        └── points3D.txt
```

同时点云会输出到：

```text
~/catkin_ws/src/FAST-LIVO2/Log/pcd
```

常见文件包括：

```text
all_raw_points.pcd
all_downsampled_points.pcd
lidar_poses.txt
```

## 二、运行 FAST-LIVO2 并生成 COLMAP 数据

启动前确认：

- 雷达驱动正常发布 `/livox/lidar`。
- 相机驱动正常发布 `/left_camera/image`。
- FAST-LIVO2 可以正常运行。
- `camera_pinhole.yaml` 中的图像尺寸和相机实际输出一致。
- `avia.yaml` 或后续 `mid360.yaml` 中的外参已经完成标定。

启动 FAST-LIVO2：

```bash
export LD_LIBRARY_PATH=/lib/x86_64-linux-gnu:/usr/lib/x86_64-linux-gnu:/opt/MVS/lib/64:/opt/MVS/lib/32:$LD_LIBRARY_PATH
source ~/catkin_ws/devel/setup.bash
roslaunch fast_livo mapping_avia.launch
```

如果已经创建了正式 MID360 配置，则改为：

```bash
roslaunch fast_livo mapping_mid360.launch
```

也可以使用一键启动脚本：

```bash
cd ~/Three-dimensional-scanner-hardware
./scripts/start_fast_livo_mid360.sh
```

运行一段时间后，正常退出 FAST-LIVO2。退出时会保存点云和 COLMAP 输出。

## 三、检查输出文件

检查 COLMAP 输出目录：

```bash
ls ~/catkin_ws/src/FAST-LIVO2/Log/Colmap
ls ~/catkin_ws/src/FAST-LIVO2/Log/Colmap/images
ls ~/catkin_ws/src/FAST-LIVO2/Log/Colmap/sparse/0
```

应能看到：

```text
cameras.txt
images.txt
points3D.txt
```

检查图像数量：

```bash
find ~/catkin_ws/src/FAST-LIVO2/Log/Colmap/images -type f -name '*.png' | wc -l
```

检查点云文件：

```bash
ls ~/catkin_ws/src/FAST-LIVO2/Log/pcd
```

如果 `images` 目录为空，通常说明 FAST-LIVO2 没有进入有效 VIO 图像处理流程，需要回头检查相机话题、图像尺寸、相机内参和外参。

## 四、在 Windows 上安装 Postshot

Windows 电脑建议使用带 NVIDIA 显卡的机器运行 Postshot。采集机仍然可以是 Ubuntu/ROS 环境，负责运行 FAST-LIVO2 并导出 `Log/Colmap`；Windows 电脑只负责导入数据、训练和查看高斯泼溅结果。

安装步骤：

1. 打开 Postshot 官网，下载 Windows 安装包。
2. 按安装向导完成安装。
3. 启动 Postshot，确认软件可以正常打开。

如果使用笔记本电脑，建议插电并在 NVIDIA 控制面板或 Windows 图形设置中让 Postshot 使用独立显卡。

## 五、在 Windows 上准备 Postshot 工程目录

建议在 Windows 上建立单独的工程目录，避免直接修改 FAST-LIVO2 原始输出。本文统一以 `D:\colmap_projects\fast_livo_mid360` 为示例路径。

如果你的实际工程在 E 盘，例如：

```text
E:\colmap_projects\fast_livo_mid360
```

后续命令中的 `D:` 直接替换为 `E:` 即可，其他目录结构保持不变。

在 PowerShell 中创建目录：

```powershell
New-Item -ItemType Directory -Force "D:\colmap_projects\fast_livo_mid360" | Out-Null
```

将采集机上的 FAST-LIVO2 输出复制到该目录，最终结构应为：

```text
D:\colmap_projects\fast_livo_mid360
├── images
│   ├── 00001.png
│   ├── 00002.png
│   └── ...
├── sparse
│   └── 0
│       ├── cameras.txt
│       ├── images.txt
│       └── points3D.txt
└── pcd
    └── ...
```

其中 `pcd` 目录不是 Postshot 导入 COLMAP 格式数据的必需目录，只是为了保留 FAST-LIVO2 输出的点云结果。

## 六、将 FAST-LIVO2 数据复制到 Windows

如果采集机和 Windows 电脑在同一局域网，可以在采集机上打包：

```bash
mkdir -p ~/colmap_projects/fast_livo_mid360
cp -r ~/catkin_ws/src/FAST-LIVO2/Log/Colmap/images ~/colmap_projects/fast_livo_mid360/
cp -r ~/catkin_ws/src/FAST-LIVO2/Log/Colmap/sparse ~/colmap_projects/fast_livo_mid360/
mkdir -p ~/colmap_projects/fast_livo_mid360/pcd
cp ~/catkin_ws/src/FAST-LIVO2/Log/pcd/*.pcd ~/colmap_projects/fast_livo_mid360/pcd/
cd ~/colmap_projects
tar -czf fast_livo_mid360_colmap.tar.gz fast_livo_mid360
```

将 `fast_livo_mid360_colmap.tar.gz` 复制到 Windows，例如放到：

```text
D:\colmap_projects\fast_livo_mid360_colmap.tar.gz
```

在 Windows PowerShell 中解压：

```powershell
New-Item -ItemType Directory -Force "D:\colmap_projects" | Out-Null
tar -xzf "D:\colmap_projects\fast_livo_mid360_colmap.tar.gz" -C "D:\colmap_projects"
```

如果不想打包，也可以用 U 盘、移动硬盘或局域网共享，直接把 `Log/Colmap/images` 和 `Log/Colmap/sparse` 复制到 Windows 工程目录中。

检查文件是否完整：

```powershell
Get-ChildItem "D:\colmap_projects\fast_livo_mid360\images" -File | Measure-Object
Get-ChildItem "D:\colmap_projects\fast_livo_mid360\sparse\0"
```

`sparse\0` 中至少应包含：

```text
cameras.txt
images.txt
points3D.txt
```

## 七、导入 Postshot 进行高斯泼溅重建

启动 Postshot 后，新建工程或选择导入数据。导入时选择工程根目录：

```text
D:\colmap_projects\fast_livo_mid360
```

Postshot 需要识别下面两个核心目录：

```text
D:\colmap_projects\fast_livo_mid360\images
D:\colmap_projects\fast_livo_mid360\sparse\0
```

其中：

- `images` 保存 FAST-LIVO2 输出的图像。
- `sparse\0\cameras.txt` 保存相机模型和内参。
- `sparse\0\images.txt` 保存每张图像对应的相机位姿。
- `sparse\0\points3D.txt` 保存稀疏点云，可以作为初始空间参考。

导入后，优先检查 Postshot 中是否能正确读取相机数量和图像数量。如果图像数量为 0，或相机轨迹明显异常，不要直接开始正式训练，应先回到文件检查步骤。

训练时建议先使用较低质量或快速预览设置跑一轮，确认相机轨迹、图像曝光和整体场景方向正常，再提高训练质量。第一次测试的目标不是追求最高画质，而是确认数据链路正确。

## 八、查看和判断重建效果

训练完成后，在 Postshot 内查看高斯泼溅结果。重点观察：

- 场景主体是否稳定，不应大面积重影。
- 转动视角时，物体边缘不应严重撕裂。
- 地面、墙面、桌面等平面不应出现大面积漂浮物。
- 颜色应与原始图像接近，不应整体偏暗、偏色或闪烁。
- 相机轨迹附近的局部区域通常效果最好，离轨迹太远或纹理太少的区域可能较差。

如果需要导出结果，按照 Postshot 的导出功能保存高斯模型或渲染结果。具体导出格式以后续使用软件为准。

## 九、Windows 常见问题

### 1. Postshot 导入后没有图像

检查：

```powershell
Get-Content "D:\colmap_projects\fast_livo_mid360\sparse\0\images.txt" -TotalCount 20
Get-ChildItem "D:\colmap_projects\fast_livo_mid360\images" -File | Select-Object -First 10
```

`images.txt` 中的图像名必须和 `images\` 目录中的文件名一致，例如：

```text
00001.png
00002.png
```

### 2. 图像尺寸或相机内参不一致

检查 `cameras.txt` 中记录的图像宽高：

```powershell
Get-Content "D:\colmap_projects\fast_livo_mid360\sparse\0\cameras.txt" -TotalCount 20
```

再查看实际图像尺寸。可以右键图片查看属性，也可以用 Python 检查：

```powershell
python -c "from PIL import Image; im=Image.open(r'D:\colmap_projects\fast_livo_mid360\images\00001.png'); print(im.size)"
```

如果没有 Pillow：

```powershell
pip install pillow
```

`cameras.txt` 中的宽高必须和图像实际尺寸一致。若相机驱动使用了 `image_scale: 0.5`，但 FAST-LIVO2 相机配置仍是 `1280 x 1024`，就会出现尺寸不一致。

### 3. 路径中有中文或空格导致导入失败

Windows 下建议把 COLMAP 工程放在纯英文路径中，例如：

```text
D:\colmap_projects\fast_livo_mid360
```

如果必须使用带空格的路径，PowerShell 命令中的路径一定要加双引号。

### 4. 高斯泼溅重建效果很差

常见原因：

- 相机内参不准确。
- 雷达-相机外参不准确。
- 图像模糊、过曝或纹理太少。
- FAST-LIVO2 轨迹漂移。
- 图像数量不足、视角变化不合适或运动速度太快。
- 使用 `mapping_avia.launch` 示例配置测试，而不是正式 MID360 标定配置。
- 画面中存在大量动态物体。
- 场景纹理太少，例如白墙、玻璃、反光金属表面。

### 5. 坐标尺度或方向看起来异常

FAST-LIVO2 输出的 COLMAP 格式模型使用 FAST-LIVO2 估计的位姿和地图坐标。若坐标方向、尺度或外参填写不正确，导入 Postshot 后可能出现相机朝向异常、场景漂移、重影或投影错位。应优先回到 FAST-LIVO2 中检查外参、相机内参和轨迹质量。

## 十、推荐流程

建议按下面顺序处理：

```text
1. 在 Ubuntu 采集机上完成相机内参标定
2. 在 Ubuntu 采集机上完成雷达-相机外参标定
3. 使用正式 MID360 配置运行 FAST-LIVO2
4. 确认 FAST-LIVO2 输出 Log/Colmap
5. 将 images、sparse 和可选 pcd 打包或复制到 Windows 电脑
6. 在 Windows 上解压到 D:\colmap_projects\fast_livo_mid360
7. 在 Postshot 中导入 D:\colmap_projects\fast_livo_mid360
8. 确认图像数量、相机数量和轨迹方向正常
9. 先用快速预览设置训练一轮
10. 确认效果后再提高训练质量并导出结果
```

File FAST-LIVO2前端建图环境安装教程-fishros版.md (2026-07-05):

# FAST-LIVO2 前端建图环境安装教程（fishros 版）

本文档用于在 Ubuntu 20.04 环境下安装 ROS Noetic，并配置、编译 FAST-LIVO2 的基础算法环境。

本文档只面向 Livox MID360 前端建图设备方案。MID360、海康相机、硬件同步器和 ROS 驱动安装见下一篇：

```text
FAST-LIVO2前端建图硬件同步器与驱动安装-MID360版.md
```

与原教程相比，本文档做了两处调整：

- 删除 Zsh / Oh My Zsh 终端环境配置部分。
- 将 ROS Noetic 手动安装流程替换为 fishros 一键安装。

适用环境：

- Ubuntu 20.04
- ROS Noetic
- FAST-LIVO2
- Livox MID360
- 海康工业相机

## 一、安装 ROS Noetic

推荐使用 fishros 一键安装工具安装 ROS Noetic。

打开终端，执行：

```bash
wget http://fishros.com/install -O fishros && . fishros
```

进入菜单后，按提示选择：

```text
1. 一键安装 ROS
1. 更换系统源再继续安装（推荐）
2. 更换系统源并清理第三方源（推荐）
选择 ROS1 Noetic
选择桌面版 / desktop-full 版本
```

不同版本的一键安装脚本菜单编号可能会变化，请以终端实际显示为准。核心目标是安装：

```text
ROS1 Noetic
```

安装完成后，新开一个终端，检查 ROS 是否可用：

```bash
roscore
```

如果可以正常启动，并看到类似 `started roslaunch server` 的输出，说明 ROS Noetic 安装成功。

如需测试图形界面，可以打开三个终端分别运行：

```bash
roscore
```

```bash
rosrun turtlesim turtlesim_node
```

```bash
rosrun turtlesim turtle_teleop_key
```

## 二、安装基础工具和编译依赖

执行：

```bash
sudo apt update
sudo apt install -y \
  git \
  vim \
  cmake \
  build-essential \
  python3-rosinstall \
  python3-rosinstall-generator \
  python3-wstool \
  python3-catkin-tools
```

确认 ROS 环境变量已经加载：

```bash
echo $ROS_DISTRO
```

正常情况下应输出：

```text
noetic
```

如果没有输出，可以手动执行：

```bash
source /opt/ros/noetic/setup.bash
```

并写入 `~/.bashrc`：

```bash
echo "source /opt/ros/noetic/setup.bash" >> ~/.bashrc
source ~/.bashrc
```

## 三、检查 FAST-LIVO2 依赖

FAST-LIVO2 通常需要以下依赖：

- PCL >= 1.8
- Eigen >= 3.3.4
- OpenCV >= 4.2

安装 ROS Noetic 后，通常已经包含满足要求的版本。可以用下面命令检查。

检查 PCL：

```bash
apt-cache show libpcl-dev | grep Version
```

检查 Eigen：

```bash
pkg-config --modversion eigen3
```

检查 OpenCV：

```bash
pkg-config --modversion opencv4
```

Ubuntu 20.04 + ROS Noetic 常见版本为：

```text
PCL:    1.10.x
Eigen:  3.3.7
OpenCV: 4.2.0
```

## 四、编译安装 Sophus

FAST-LIVO2 依赖 Sophus。执行：

```bash
cd ~
git clone https://github.com/strasdat/Sophus.git
cd Sophus
git checkout a621ff
```

如果编译时报 Eigen 相关错误，需要修改 `sophus/so2.cpp`。

打开文件：

```bash
vim sophus/so2.cpp
```

找到类似下面的代码：

```cpp
unit_complex_.real() = 1.;
unit_complex_.imag() = 0.;
```

修改为：

```cpp
unit_complex_.real(1.);
unit_complex_.imag(0.);
```

然后编译安装：

```bash
mkdir -p build
cd build
cmake ..
make -j$(nproc)
sudo make install
```

如果电脑内存较小，可以将 `make -j$(nproc)` 改为：

```bash
make -j2
```

## 五、创建 Catkin 工作空间

执行：

```bash
mkdir -p ~/catkin_ws/src
cd ~/catkin_ws/src
```

下载依赖仓库：

```bash
git clone https://github.com/xuankuzcr/rpg_vikit.git
```

下载 FAST-LIVO2：

```bash
git clone https://github.com/hku-mars/FAST-LIVO2.git
```

## 六、编译 FAST-LIVO2

回到工作空间根目录：

```bash
cd ~/catkin_ws
```

安装工作空间依赖：

```bash
rosdepc install --from-paths src --ignore-src -r -y
```

编译：

```bash
catkin_make
```

如果电脑内存较小，可以限制编译线程：

```bash
catkin_make -j2
```

编译完成后，加载工作空间环境：

```bash
source ~/catkin_ws/devel/setup.bash
```

建议写入 `~/.bashrc`，方便以后自动加载：

```bash
echo "source ~/catkin_ws/devel/setup.bash" >> ~/.bashrc
source ~/.bashrc
```

## 七、检查 FAST-LIVO2 环境

编译完成后，可以先检查 ROS 是否能识别 FAST-LIVO2 包：

```bash
source ~/catkin_ws/devel/setup.bash
rospack find fast_livo
```

如果输出 FAST-LIVO2 的本地路径，说明工作空间已经被 ROS 正确识别。

继续检查 launch 文件是否存在：

```bash
roscd fast_livo
ls launch
```

注意：FAST-LIVO2 官方仓库默认提供的是 AVIA 示例配置。本文档面向 MID360，不建议把 `mapping_avia.launch` 直接当作 MID360 最终配置使用。

完成本篇后，继续进行 MID360、海康相机、硬件同步器和 ROS 驱动安装。

## 八、常见问题

### 1. 终端提示找不到 roscore / roslaunch

说明 ROS 环境变量没有加载。执行：

```bash
source /opt/ros/noetic/setup.bash
```

如果已经编译了工作空间，再执行：

```bash
source ~/catkin_ws/devel/setup.bash
```

### 2. catkin_make 找不到 FAST-LIVO2 包

确认 FAST-LIVO2 是否在 `~/catkin_ws/src` 目录下：

```bash
ls ~/catkin_ws/src
```

目录结构应类似：

```text
catkin_ws
└── src
    ├── FAST-LIVO2
    └── rpg_vikit
```

### 3. 编译时内存不足或卡死

使用较少线程重新编译：

```bash
cd ~/catkin_ws
catkin_make -j2
```

### 4. rosdep 相关问题

fishros 一键安装通常会自动处理 rosdep / rosdepc。如果仍然遇到依赖问题，可以尝试：

```bash
sudo apt install -y python3-pip
sudo pip3 install rosdepc
sudo rosdepc init
rosdepc update
```

然后在工作空间中安装依赖：

```bash
cd ~/catkin_ws
rosdepc install --from-paths src --ignore-src -r -y
```

## 九、参考链接

- FAST-LIVO2: https://github.com/hku-mars/FAST-LIVO2
- rpg_vikit: https://github.com/xuankuzcr/rpg_vikit
- Sophus: https://github.com/strasdat/Sophus
- fishros 一键安装工具: https://fishros.github.io/install/
- 原教程页面: https://www.scan2.world/blog/1

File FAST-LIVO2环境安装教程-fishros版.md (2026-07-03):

# FAST-LIVO2 手持设备环境安装教程（fishros 版）

本文档用于在 Ubuntu 20.04 环境下安装 ROS Noetic，并配置、编译、运行 FAST-LIVO2。

与原教程相比，本文档做了两处调整：

- 删除 Zsh / Oh My Zsh 终端环境配置部分。
- 将 ROS Noetic 手动安装流程替换为 fishros 一键安装。

适用环境：

- Ubuntu 20.04
- ROS Noetic
- FAST-LIVO2
- Livox Avia 或兼容数据包

## 一、安装 ROS Noetic

推荐使用 fishros 一键安装工具安装 ROS Noetic。

打开终端，执行：

```bash
wget http://fishros.com/install -O fishros && . fishros
```

进入菜单后，按提示选择：

```text
1. 一键安装 ROS
1. 更换系统源再继续安装（推荐）
2. 更换系统源并清理第三方源（推荐）
选择 ROS1 Noetic
选择桌面版 / desktop-full 版本
```

不同版本的一键安装脚本菜单编号可能会变化，请以终端实际显示为准。核心目标是安装：

```text
ROS1 Noetic
```

安装完成后，新开一个终端，检查 ROS 是否可用：

```bash
roscore
```

如果可以正常启动，并看到类似 `started roslaunch server` 的输出，说明 ROS Noetic 安装成功。

如需测试图形界面，可以打开三个终端分别运行：

```bash
roscore
```

```bash
rosrun turtlesim turtlesim_node
```

```bash
rosrun turtlesim turtle_teleop_key
```

## 二、安装基础工具和编译依赖

执行：

```bash
sudo apt update
sudo apt install -y \
  git \
  vim \
  cmake \
  build-essential \
  python3-rosinstall \
  python3-rosinstall-generator \
  python3-wstool \
  python3-catkin-tools
```

确认 ROS 环境变量已经加载：

```bash
echo $ROS_DISTRO
```

正常情况下应输出：

```text
noetic
```

如果没有输出，可以手动执行：

```bash
source /opt/ros/noetic/setup.bash
```

并写入 `~/.bashrc`：

```bash
echo "source /opt/ros/noetic/setup.bash" >> ~/.bashrc
source ~/.bashrc
```

## 三、检查 FAST-LIVO2 依赖

FAST-LIVO2 通常需要以下依赖：

- PCL >= 1.8
- Eigen >= 3.3.4
- OpenCV >= 4.2

安装 ROS Noetic 后，通常已经包含满足要求的版本。可以用下面命令检查。

检查 PCL：

```bash
apt-cache show libpcl-dev | grep Version
```

检查 Eigen：

```bash
pkg-config --modversion eigen3
```

检查 OpenCV：

```bash
pkg-config --modversion opencv4
```

Ubuntu 20.04 + ROS Noetic 常见版本为：

```text
PCL:    1.10.x
Eigen:  3.3.7
OpenCV: 4.2.0
```

## 四、编译安装 Sophus

FAST-LIVO2 依赖 Sophus。执行：

```bash
cd ~
git clone https://github.com/strasdat/Sophus.git
cd Sophus
git checkout a621ff
```

如果编译时报 Eigen 相关错误，需要修改 `sophus/so2.cpp`。

打开文件：

```bash
vim sophus/so2.cpp
```

找到类似下面的代码：

```cpp
unit_complex_.real() = 1.;
unit_complex_.imag() = 0.;
```

修改为：

```cpp
unit_complex_.real(1.);
unit_complex_.imag(0.);
```

然后编译安装：

```bash
mkdir build
cd build
cmake ..
make -j$(nproc)
sudo make install
```

## 五、创建 Catkin 工作空间

执行：

```bash
mkdir -p ~/catkin_ws/src
cd ~/catkin_ws/src
```

下载依赖仓库：

```bash
git clone https://github.com/xuankuzcr/rpg_vikit.git
```

下载 FAST-LIVO2：

```bash
git clone https://github.com/hku-mars/FAST-LIVO2.git
```

## 六、编译 FAST-LIVO2

回到工作空间根目录：

```bash
cd ~/catkin_ws
```

编译：

```bash
catkin_make
```

如果电脑内存较小，可以限制编译线程：

```bash
catkin_make -j2
```

编译完成后，加载工作空间环境：

```bash
source ~/catkin_ws/devel/setup.bash
```

建议写入 `~/.bashrc`，方便以后自动加载：

```bash
echo "source ~/catkin_ws/devel/setup.bash" >> ~/.bashrc
source ~/.bashrc
```

## 七、运行 FAST-LIVO2 示例

先准备好 FAST-LIVO2 支持的数据包，例如 Livox Avia 的 rosbag。

启动算法：

```bash
roslaunch fast_livo mapping_avia.launch
```

新开一个终端，播放数据包：

```bash
rosbag play YOUR_DOWNLOADED.bag
```

请将 `YOUR_DOWNLOADED.bag` 替换为实际 rosbag 文件路径，例如：

```bash
rosbag play ~/bags/avia_demo.bag
```

如果配置正常，RViz 中会显示实时构建的点云地图和轨迹。

## 八、常见问题

### 1. 终端提示找不到 roscore / roslaunch

说明 ROS 环境变量没有加载。执行：

```bash
source /opt/ros/noetic/setup.bash
```

如果已经编译了工作空间，再执行：

```bash
source ~/catkin_ws/devel/setup.bash
```

### 2. catkin_make 找不到 FAST-LIVO2 包

确认 FAST-LIVO2 是否在 `~/catkin_ws/src` 目录下：

```bash
ls ~/catkin_ws/src
```

目录结构应类似：

```text
catkin_ws
└── src
    ├── FAST-LIVO2
    └── rpg_vikit
```

### 3. 编译时内存不足或卡死

使用较少线程重新编译：

```bash
cd ~/catkin_ws
catkin_make -j2
```

### 4. rosdep 相关问题

fishros 一键安装通常会自动处理 rosdep / rosdepc。如果仍然遇到依赖问题，可以尝试：

```bash
sudo apt install -y python3-pip
sudo pip3 install rosdepc
sudo rosdepc init
rosdepc update
```

然后在工作空间中安装依赖：

```bash
cd ~/catkin_ws
rosdepc install --from-paths src --ignore-src -r -y
```

## 九、参考链接

- FAST-LIVO2: https://github.com/hku-mars/FAST-LIVO2
- rpg_vikit: https://github.com/xuankuzcr/rpg_vikit
- Sophus: https://github.com/strasdat/Sophus
- fishros 一键安装工具: https://fishros.github.io/install/
- 原教程页面: https://www.scan2.world/blog/1

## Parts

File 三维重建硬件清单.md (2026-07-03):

# 手持三维重建硬件清单

文档顺序：1

本文档按“手持式激光雷达 + 相机融合三维重建”方案整理。系统通过激光雷达获取空间点云，通过相机获取纹理/视觉特征，通过时间同步器保证雷达与相机数据在时间上对齐，再通过标定板完成雷达-相机外参标定和相机内参标定。

## 1. 核心硬件清单

| 序号 | 硬件名称 | 推荐型号/购买关键词 | 关键参数建议 | 数量 | 估计单价 | 淘宝搜索链接 |
|---:|---|---|---|---:|---:|---|
| 1 | 雷达 | Livox Mid-360 | 905 nm，Class 1 人眼安全；水平 360°、竖直 -7°~52°；0.1 m 盲区；20 万点/秒；支持 PTPv2/GPS 同步；9-27 V DC 供电 | 1 | 3000-5000 元 | https://s.taobao.com/search?q=Livox+Mid-360+%E6%BF%80%E5%85%89%E9%9B%B7%E8%BE%BE |
| 2 | 雷达一分三线 | Livox Mid-360 一分三线 / Mid-360 电源网口同步线 | 通常包含电源、以太网数据、同步/控制接口；必须匹配 Mid-360 接口定义和针脚 | 1 | 100-500 元 | https://s.taobao.com/search?q=Livox+Mid-360+%E4%B8%80%E5%88%86%E4%B8%89%E7%BA%BF |
| 3 | 相机 | 海康威视 MV-CU013-A0UC | 130 万像素 USB3.0 彩色工业相机；CMOS 全局快门；1280 x 1024；最高约 201.4 fps；支持外触发 | 1 | 800-2000 元 | https://s.taobao.com/search?q=MV-CU013-A0UC+%E6%B5%B7%E5%BA%B7+%E5%B7%A5%E4%B8%9A%E7%9B%B8%E6%9C%BA |
| 4 | 镜头 | 海康 MVL-HF0628M-6MPE | C 口；6 mm；1/1.8 英寸；6MP；F2.8-F16；手动光圈/对焦；最近摄距 0.1 m | 1 | 300-1000 元 | https://s.taobao.com/search?q=MVL-HF0628M-6MPE |
| 5 | 相机数据线 | USB3.0 工业相机数据线 / GigE 网线 | USB3.0 相机建议使用带锁紧螺丝的数据线；GigE 相机建议使用六类网线或工业网线 | 1 | 50-300 元 | https://s.taobao.com/search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 |
| 6 | 相机信号线 | 工业相机 I/O 触发线 / 6pin 12pin 航插线 | 用于外触发、曝光同步、GPIO 输入输出；需与相机接口针脚匹配 | 1 | 50-300 元 | https://s.taobao.com/search?q=%E5%B7%A5%E4%B8%9A%E7%9B%B8%E6%9C%BA+%E8%A7%A6%E5%8F%91%E7%BA%BF+IO%E7%BA%BF |
| 7 | 主机 | Intel NUC11PAHi7000 / NUC11PAHi7，i7-1165G7 | 11 代 i7-1165G7；建议 16-32 GB 内存、512 GB 以上 SSD；需要千兆网口和 USB3.0；推荐 Ubuntu/ROS 环境 | 1 | 2500-5000 元 | https://s.taobao.com/search?q=NUC11PAHi7000+i7+1165G7 |
| 8 | 充电宝 | 酷态科 15 号 Ultra / PB200U | 20000 mAh 级；总输出最高 210 W；USB-C1 最高 140 W，USB-C2 最高 90 W；支持 PD3.1；给 NUC 供电需确认 19 V/20 V 诱骗线或转换模块 | 1 | 400-800 元 | https://s.taobao.com/search?q=%E9%85%B7%E6%80%81%E7%A7%91+15%E5%8F%B7+Ultra |
| 9 | 雷达供电线 | Mid-360 雷达 DC 供电线 / 一分三线电源输入线 / DC 转接线 | 用于从移动电源、DC 转换模块或同步器供电端给 Mid-360 供电；需匹配 9-27 V DC、接口针脚、极性和线径，建议带保险或独立开关 | 1 | 30-200 元 | https://s.taobao.com/search?q=Livox+Mid-360+%E4%BE%9B%E7%94%B5%E7%BA%BF |
| 10 | 主机供电诱骗线 | USB-C PD 诱骗线转 DC 圆口 / 20 V PD 诱骗线 / NUC 供电线 | 用于从酷态科 15 号 Ultra 的 USB-C 输出给 NUC 供电；需确认 NUC 圆口规格、中心正负极、19 V/20 V 电压和 65 W 以上功率余量 | 1 | 30-150 元 | https://s.taobao.com/search?q=NUC+20V+PD%E8%AF%B1%E9%AA%97%E7%BA%BF |
| 11 | 雷达相机支架 | `雷达相机支架/mid360-1.stl` + `雷达相机支架/mid360-2.stl` | 采用文件夹内 STL 模型进行 3D 打印；需要保证雷达与相机刚性连接，打印后检查安装孔位、装配间隙和固定强度；固定后不能晃动 | 1 套 | 按 3D 打印报价 | 本地文件夹：`雷达相机支架` |
| 12 | 整体外壳 | 手持三维重建设备外壳 / 3D 打印外壳 / CNC 外壳 | 需要容纳雷达、相机、同步器、线缆和散热空间；建议预留手柄、散热孔、安装孔和检修口 | 1 | 200-2000 元 | coming soon |
| 13 | 雷达相机标定板 | LiDAR-Camera 联合标定板 / AprilTag 标定板 / 棋盘格反光标定板 | 用于求雷达坐标系到相机坐标系的外参；建议尺寸 600 mm x 800 mm 以上，平整、刚性好、图案清晰 | 1 | 100-1000 元 | https://s.taobao.com/search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 |
| 14 | 相机内参标定板 | OpenCV 棋盘格标定板 / 圆点标定板 / AprilGrid 标定板 | 用于标定焦距、主点、畸变系数；建议选择玻璃、铝塑板或亚克力硬板，格子尺寸 20-40 mm | 1 | 30-500 元 | https://s.taobao.com/search?q=OpenCV+%E7%9B%B8%E6%9C%BA+%E5%86%85%E5%8F%82+%E6%A0%87%E5%AE%9A%E6%9D%BF |
| 15 | 雷达相机时间同步器 | Fast-LIVO2 硬件时间同步器 | 适配 Livox Mid-360 和海康 MV-CU013-A0UC；用于相机硬触发和雷达相机时间戳对齐；购买前确认接口线序和电平 | 1 | 300-1500 元 | https://s.taobao.com/search?q=Fast-LIVO2+%E7%A1%AC%E4%BB%B6%E6%97%B6%E9%97%B4%E5%90%8C%E6%AD%A5%E5%99%A8 |

## 2. 关键参数选择建议

### 雷达

- 优先选择 3D 激光雷达，不建议使用单线 2D 雷达作为主扫描传感器。
- 手持三维重建更看重近距离盲区、视场角、重量和点频。
- 雷达必须能稳定输出点云数据，并且最好支持 PTP、PPS 或 GPS 时间同步。
- 如果用于室内建图，视场角大、近距离盲区小的雷达更合适。

### 相机和镜头

- 相机建议选全局快门，减少手持运动造成的图像变形。
- 如果需要彩色点云，选择彩色工业相机。
- 镜头焦距需要根据扫描距离选择：近距离大场景可选 4 mm/6 mm，中距离可选 8 mm/12 mm。
- 镜头固定后不要频繁调整焦距和光圈，否则需要重新标定内参。

### 时间同步器

- 相机支持外触发时，可以由同步器输出 TTL 脉冲触发曝光。
- 雷达支持 PTP 时，可通过 PTP 主时钟进行网络时间同步。
- 雷达支持 PPS + NMEA 时，可用 PPS 秒脉冲和串口时间报文对齐时间戳。
- 输出电平必须匹配设备要求，常见有 3.3 V TTL、5 V TTL、光耦输入等。

### 结构和外壳

- 雷达和相机的相对位置必须刚性固定。
- 支架材料建议使用铝合金、碳纤维或高强度 3D 打印材料。
- 外壳要兼顾散热、走线、重量和握持舒适性。
- 标定完成后，不要再移动雷达和相机的安装位置。

## 3. 系统连接关系

```text
数据链路：
[ 相机 ] --USB3.0 数据线--------------------> [ 主机 NUC ]
[ 雷达 Livox Mid-360 ] --以太网数据线-------> [ 主机 NUC ]

同步链路：
[ 时间同步器 ] --相机触发/同步信号线--------> [ 相机 ]
[ 时间同步器 ] --雷达同步信号---------------> [ 雷达 Livox Mid-360 ]

供电链路：
[ 酷态科 15 号 Ultra 移动电源 ]
    |--主机供电诱骗线-----------------------> [ 主机 NUC ]
                                                |
                                                |--同步器供电线--------> [ 时间同步器 ]
    |--USB-C / DC 输出----------------------> [ DC 转换模块 / 电源分配 ]
                                                |
                                                |--雷达供电线----------> [ 雷达 Livox Mid-360 ]

结构固定：
[ 雷达 Livox Mid-360 ] + [ 相机 + 镜头 ] --刚性支架固定--> 完成外参标定后不再改变相对位置
```

## 4. 标定件用途

| 标定件 | 用途 | 备注 |
|---|---|---|
| 相机内参标定板 | 标定相机焦距、主点、畸变系数 | 常用棋盘格、圆点板、AprilGrid |
| 雷达相机标定板 | 标定雷达坐标系到相机坐标系的外参 | 需要让雷达点云和图像都能稳定识别标定板 |
| 尺子/卷尺 | 检查标定板尺寸和安装距离 | 用于误差检查 |

## 5. 采购注意事项

- 雷达、相机、镜头、线缆必须确认接口匹配，尤其是雷达一分三线、雷达供电线、主机供电诱骗线和相机信号线。
- 买雷达前要确认供电电压、数据接口、同步方式和 SDK 是否满足项目需求。
- 雷达到货后、安装支架或外壳前，先拍照记录雷达铭牌和序列号；后续配置 MID360 IP、核对设备和排查驱动问题时可能会用到。
- 工业相机要确认是否支持硬触发，否则时间同步只能依赖软件时间戳，误差会更大。
- 酷态科 15 号 Ultra 给 NUC 和传感器供电时，要核算总功率，并预留 30% 以上余量；NUC 通常需要稳定的 19 V/20 V 输入，主机供电诱骗线需要确认触发电压、圆口规格、极性和功率余量。
- Mid-360 供电范围为 9-27 V DC，不能直接随意接 USB 输出；雷达供电线需要按一分三线和同步器方案确认电压、极性、线序和线径。
- 外壳和支架做好后再标定；如果拆装过传感器，需要重新做雷达相机外参标定。
- 淘宝商品链接容易失效，建议用本文档的关键词搜索，并优先选择参数完整、可开发票、支持退换的店铺。

## 6. 推荐下单关键词汇总

- `Livox Mid-360 激光雷达`
- `Livox Mid-360 一分三线`
- `MV-CU013-A0UC 海康 工业相机`
- `MVL-HF0628M-6MPE 海康 镜头`
- `USB3.0 工业相机 数据线 螺丝`
- `工业相机 触发线 IO线`
- `NUC11PAHi7000 i7 1165G7`
- `酷态科 15号 Ultra PB200U`
- `Livox Mid-360 供电线`
- `NUC 20V PD诱骗线`
- `Fast-LIVO2 硬件时间同步器`
- `mid360-1.stl`
- `mid360-2.stl`
- `雷达 相机 联合标定板`
- `OpenCV 相机内参 标定板`

## 7. 参考资料

- Livox Mid-360 官方页面：https://www.livoxtech.com/cn/mid-360
- Livox Mid-360 参数页：https://www.livoxtech.com/cn/mid-360/specs
- Livox 设备时间同步说明：https://livox-wiki-cn.readthedocs.io/zh_CN/latest/tutorials/other_product/timestamp_sychronization.html
- 海康 MV-CU013-A0UC 参数资料：https://www.maxxvision.com/downloads/Cameras/USB30/Hikrobot/Hikrobot_MV-CU013-A0UMUC.pdf
- 海康 MVL-HF0628M-6MPE 镜头资料：https://uploadcdn.oneyac.com/attachments/files/brand_pdf/hikvision/6C/8A/MVL-HF0628M-6MPE_20221022.pdf
- Fast-LIVO2 时间同步器使用说明：https://www.scan2.world/blog/101
- 酷态科 15 号 Ultra 官方参数：https://cuktech.com.cn/h5/show_procon.thtml?id=219
- Intel NUC11PA 技术规格：https://www.intel.com/content/dam/support/us/en/documents/intel-nuc/NUC11PA_TechProdSpec.pdf

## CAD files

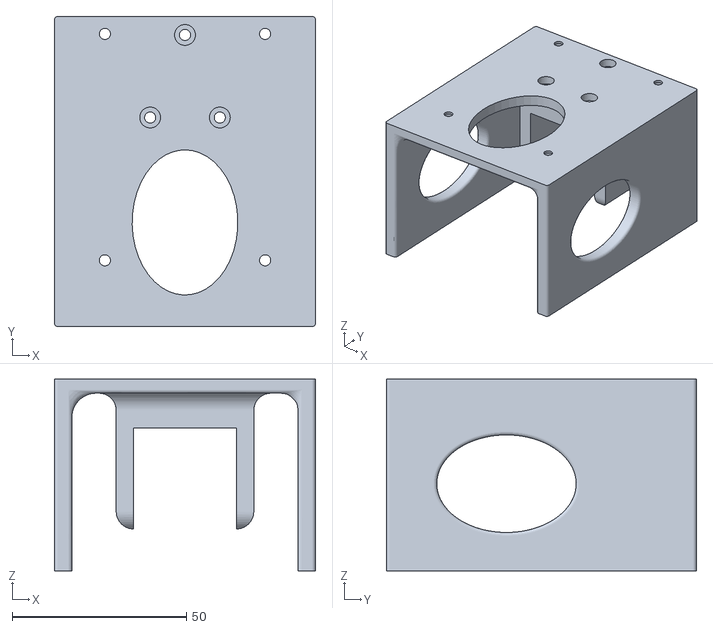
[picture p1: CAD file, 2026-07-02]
雷达相机支架/mid360-2.stl
75.0 x 89.0 x 55.0

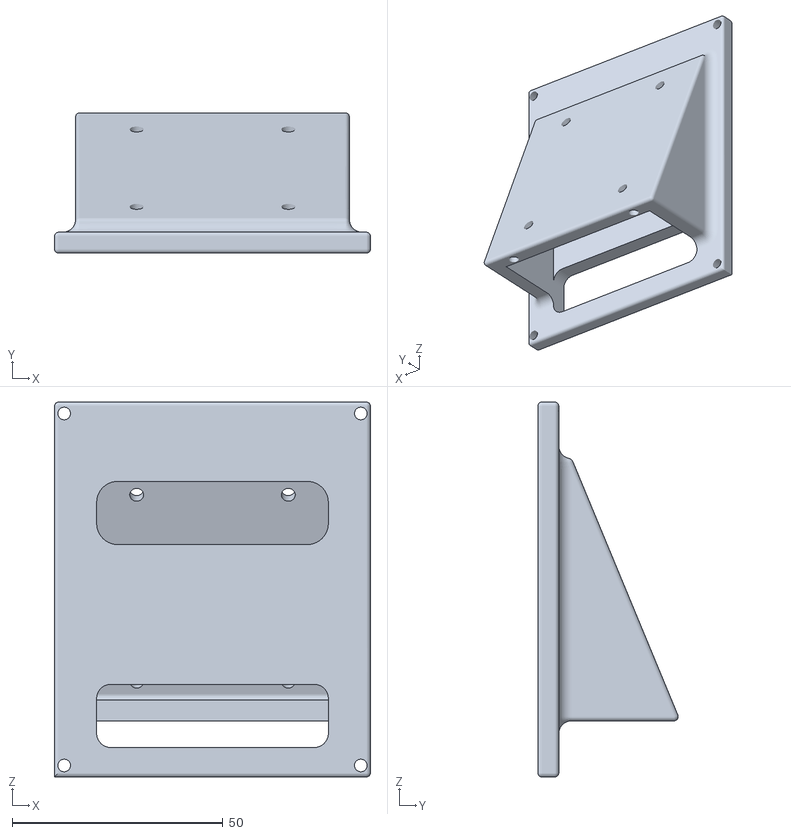
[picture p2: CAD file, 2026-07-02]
雷达相机支架/mid360-1.stl
75.0 x 33.3 x 89.0
